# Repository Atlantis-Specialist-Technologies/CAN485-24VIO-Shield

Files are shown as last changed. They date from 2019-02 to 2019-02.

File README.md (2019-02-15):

SparkFun AST-CAN485 I/O Shield (24V)
========================================

SparkFun AST-CAN485 I/O Shield (24V)

[*SparkFun AST-CAN485 I/O Shield (24V) (14598)*](https://www.sparkfun.com/products/14598)

The SparkFun AST-CAN485 I/O Shield allows you to use the [AST-CAN485 Dev Board](https://www.sparkfun.com/products/14483) with 24VDC Inputs and Outputs, a popular voltage level for industrial automation devices as well as 5v devices. By providing screw terminals, the board can easily and safely interface with I/O in a semi-permanent manner which allows for inputs, outputs, or the board itself to be swapped out. With all pins pre-populated with either females pin headers or screw terminals, setup time is minimized.

The AST-CAN485 I/O Shield provides a socket to break out all of the I/O of the AST-CAN485 Dev Board. To make a secure connection to your industrial equipment, screw terminals come pre-soldered to the board to get you up and running in no time. The AST-CAN485 I/O Shield is designed to work in the industrial 24V environment, but has a wide supply input range of 7-24V. The board comes with input reverse voltage protection with a green and red status LEDs (green means power is connected properly, and red indicates reversed power, and blocks power to the rest of the board.

Repository Contents
-------------------

* **/Documentation** - Data sheets, additional product information
* **/Hardware** - Eagle design files (.brd, .sch)
* **/Libraries** - Libraries for use with the SparkFun AST-CAN485 I/O Shield (24V)

Documentation
--------------
* **[Library](https://github.com/Atlantis-Specialist-Technologies/AST_V24IO_Arduino_Library)** - Arduino library for the SparkFun AST-CAN485 I/O Shield (24V).
* **[Hookup Guide](https://learn.sparkfun.com/tutorials/ast-can485-io-shield-24v-hookup-guide)** - Basic hookup guide for the SparkFun AST-CAN485 I/O Shield (24V).
* **[SparkFun Fritzing repo](https://github.com/sparkfun/Fritzing_Parts)** - Fritzing diagrams for SparkFun products.

License Information
-------------------

This product is _**open source**_!

Please review the LICENSE.md file for license information.

If you have any questions or concerns on licensing, please contact techsupport@sparkfun.com.

Distributed as-is; no warranty is given.

- Your friends at SparkFun, in collaboration with Atlantis Specialist Technologies

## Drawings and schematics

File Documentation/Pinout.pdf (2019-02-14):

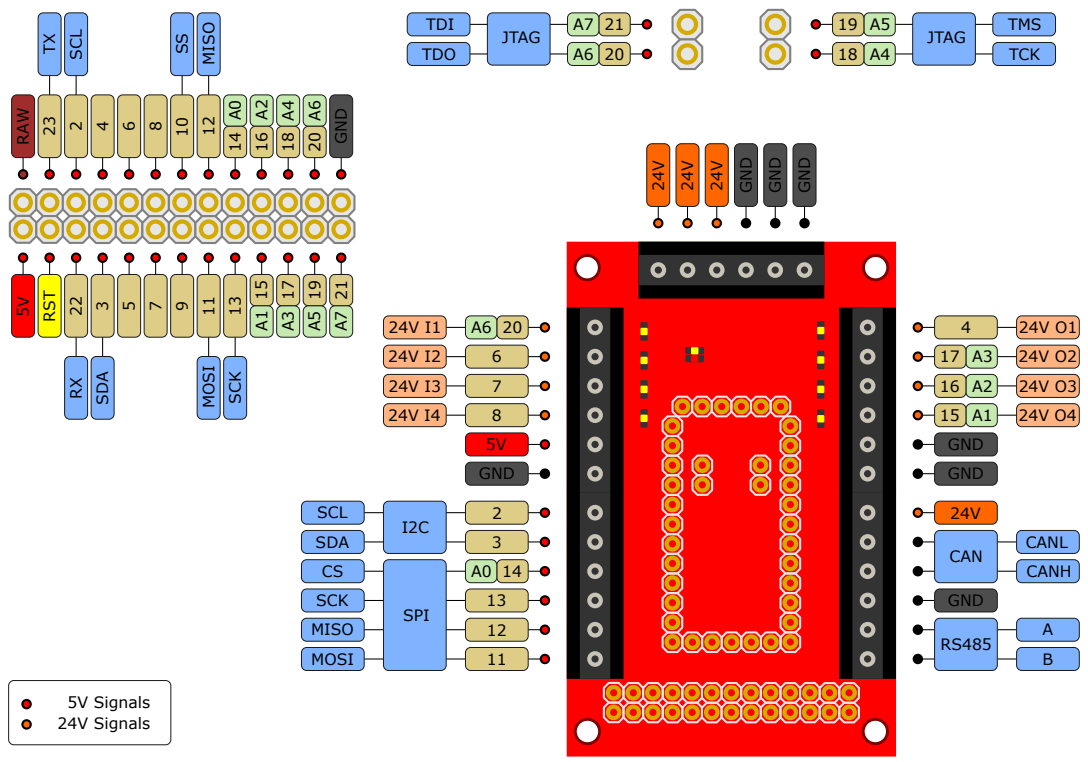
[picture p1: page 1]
TDO; TDI; JTAG; TCK; TMS; GND; CAN; CANH; CANL; SCK; MISO; MOSI; SDA; SCL; SPI; RAW; RST; 5V Signals 24V Signals

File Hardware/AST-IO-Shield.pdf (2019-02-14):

## GND

5V

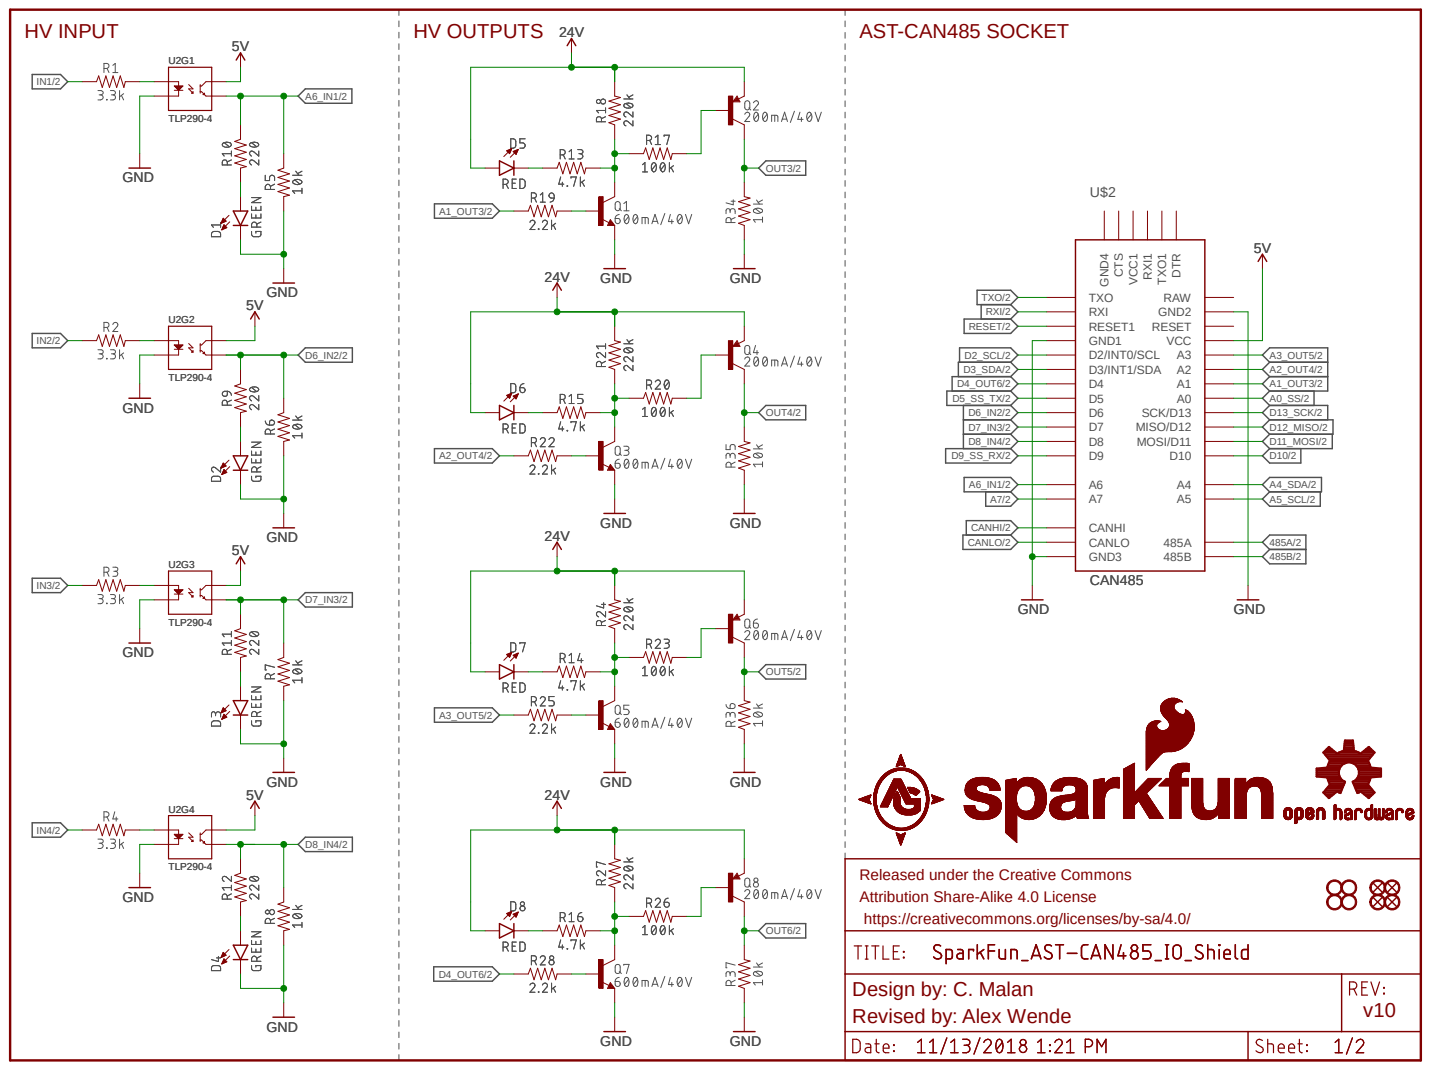
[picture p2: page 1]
GND; A0A1A2A3A4A5 CANHI CANLOCTS D2/INT0/SCL D3/INT1/SDA D4 D5 D6 D7 D8 D9; D10DTR GND1; GND2 GND3GND⁴; MISO/D12 MOSI/D11 RAW; RESET1; RESET RXI; RXI1 SCK/D13 TXO; TXO¹ VCC VCC¹; CAN485 A6A7; U2G1 TLP290-4 U2G2 TLP290-4 U2G3 TLP290-4 U2G4 TLP290-4; D4_OUT6/2; A1_OUT3/2; A2_OUT4/2; 485A/2 CANHI/2 CANLO/2; TXO/2 RXI/2 RESET/2; A3_OUT5/2; A0_SS/2 D13_SCK/2 D12_MISO/2; D11_MOSI/2 D10/2 A4_SDA/2 A7/2; A5_SCL/2; D3_SDA/2; D2_SCL/2; OUT3/2 OUT4/2 OUT5/2 OUT6/2; HV INPUT; HV OUTPUTS; AST-CAN485 SOCKET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

Released under the Creative Commons
Attribution Share-Alike 4.0 License
https://creativecommons.org/licenses/by-sa/4.0/

# VIN: 24V

# LMR14206 U1

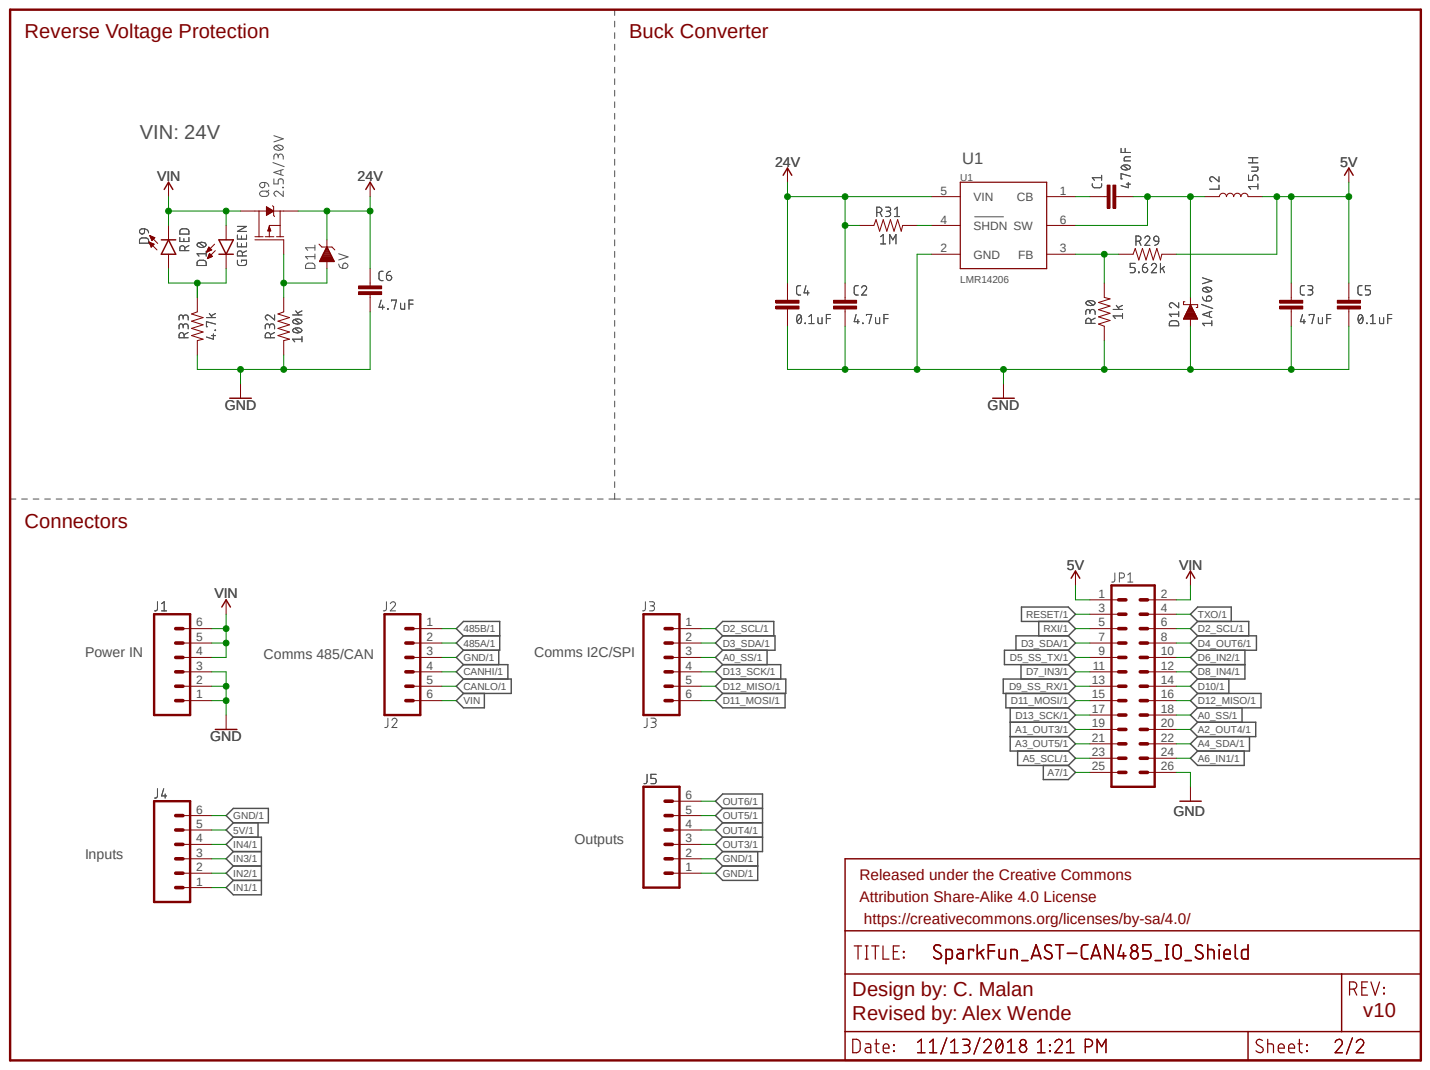
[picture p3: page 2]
Power IN; Comms 485/CAN; Comms I2C/SPI; Inputs; Outputs; GND; VIN; 3 GND 2; SHDN 4; 6 VIN 5 U1; 6 GND/1 GND/1; GND/1 GND/1; 485A/1 CANHI/1 CANLO/1; A0_SS/1 VIN; D2_SCL/1; D3_SDA/1; D13_SCK/1; D12_MISO/1; D11_MOSI/1; D4_OUT6/1; A1_OUT3/1; A2_OUT4/1 TXO/1 RXI/1 RESET/1 A3_OUT5/1; D10/1 A4_SDA/1 A7/1; A6_IN1/1 OUT3/1 OUT4/1 OUT5/1 OUT6/1; A5_SCL/1; Reverse Voltage Protection; Buck Converter; Connectors; C. Malan

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

Design by:
Revised by: Alex Wende

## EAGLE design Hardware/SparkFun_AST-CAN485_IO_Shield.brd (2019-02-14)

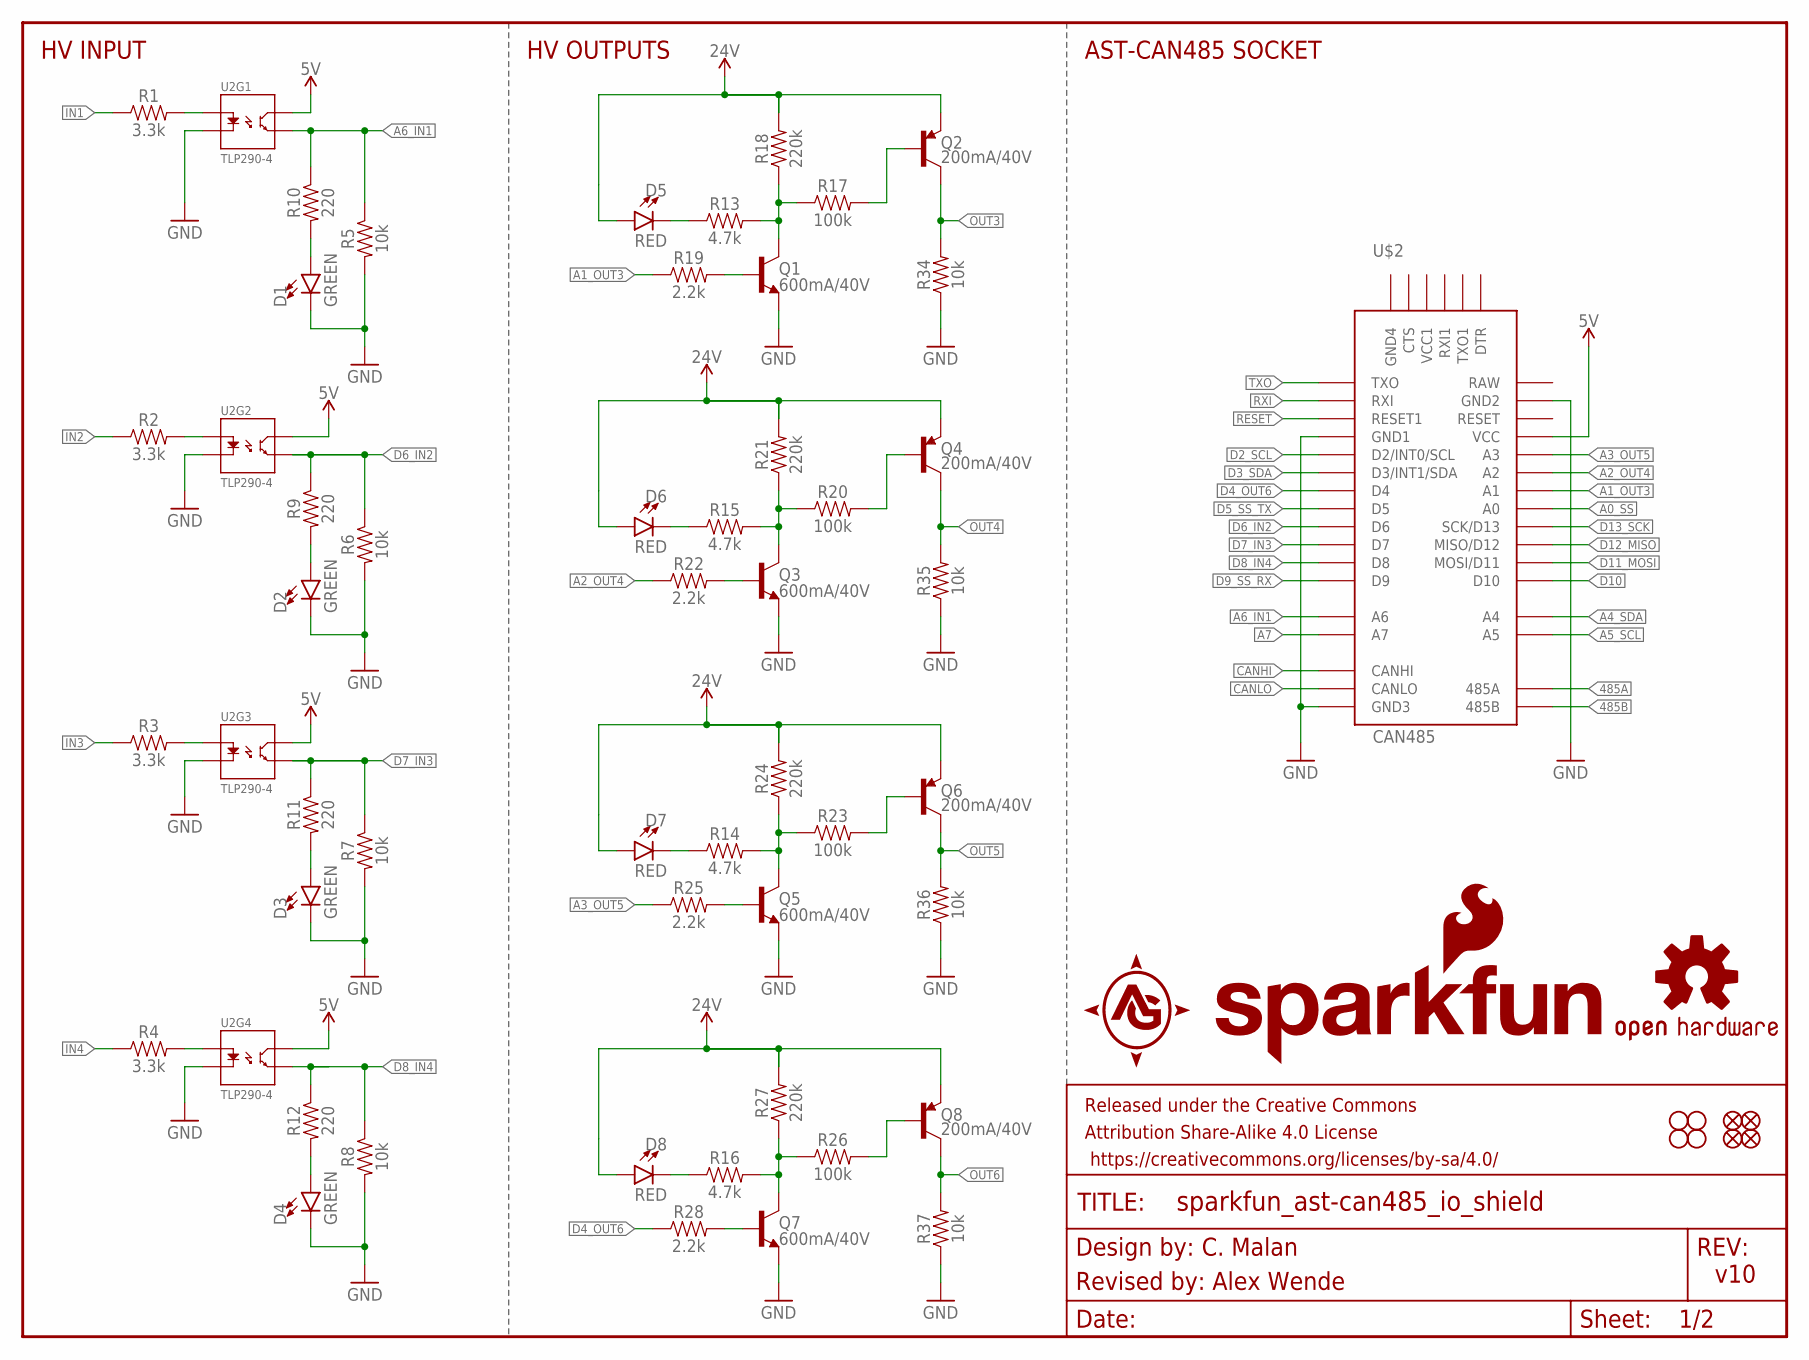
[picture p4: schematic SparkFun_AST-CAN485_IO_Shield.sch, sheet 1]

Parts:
D1, D2, D3, D4: GREEN; LED-0603
D5, D6, D7, D8: RED; LED-0603
FD1, FD2, FD3, FD4: FIDUCIALUFIDUCIAL; FIDUCIAL-MICRO
FRAME3: FRAME-LETTER; CREATIVE_COMMONS
H1, H2, H3, H4: STAND-OFF
LOGO1: OSHW-LOGOM; OSHW-LOGO-M
LOGO2: SFE_LOGO_NAME_FLAME.2_INCH; SFE_LOGO_NAME_FLAME_.2
Q1, Q3, Q5, Q7: 600mA/40V; SOT23-3
Q2, Q4, Q6, Q8: 200mA/40V; SOT23-3
R1, R2, R3, R4: 3.3k; 0603
R5, R6, R7, R8, R34, R35, R36, R37: 10k; 0603
R9, R10, R11, R12: 220; 0603
R13, R14, R15, R16: 4.7k; 0603
R17, R20, R23, R26: 100k; 0603
R18, R21, R24, R27: 220k; 0603
R19, R22, R25, R28: 2.2k; 0603
U2: TLP290-4; SO16
U$2: CAN485

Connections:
5V: U2.10 (CL1), U2.12 (CL1), U2.14 (CL1), U2.16 (CL1), U$2.VCC; also elsewhere on the board
24V: D5.A, D6.A, D7.A, D8.A, Q2.2 (E), Q4.2 (E), Q6.2 (E), Q8.2 (E), R18.2, R21.2, R24.2, R27.2; also elsewhere on the board
485A: U$2.485A; also elsewhere on the board
485B: U$2.485B; also elsewhere on the board
A0_SS: U$2.A0; also elsewhere on the board
A1_OUT3: R19.1, U$2.A1; also elsewhere on the board
A2_OUT4: R22.1, U$2.A2; also elsewhere on the board
A3_OUT5: R25.1, U$2.A3; also elsewhere on the board
A4_SDA: U$2.A4; also elsewhere on the board
A5_SCL: U$2.A5; also elsewhere on the board
A6_IN1: R5.1, R10.1, U2.15 (EM1), U$2.A6; also elsewhere on the board
A7: U$2.A7; also elsewhere on the board
CANHI: U$2.CANHI; also elsewhere on the board
CANLO: U$2.CANLO; also elsewhere on the board
D2_SCL: U$2.2 (D2/INT0/SCL); also elsewhere on the board
D3_SDA: U$2.3 (D3/INT1/SDA); also elsewhere on the board
D4_OUT6: R28.1, U$2.4 (D4); also elsewhere on the board
D5_SS_TX: U$2.5 (D5); also elsewhere on the board
D6_IN2: R6.1, R9.1, U2.13 (EM1), U$2.6 (D6); also elsewhere on the board
D7_IN3: R7.1, R11.1, U2.11 (EM1), U$2.7 (D7); also elsewhere on the board
D8_IN4: R8.1, R12.1, U2.9 (EM1), U$2.8 (D8); also elsewhere on the board
D9_SS_RX: U$2.9 (D9); also elsewhere on the board
D10: U$2.10 (D10); also elsewhere on the board
D11_MOSI: U$2.11 (MOSI/D11); also elsewhere on the board
D12_MISO: U$2.12 (MISO/D12); also elsewhere on the board
D13_SCK: U$2.13 (SCK/D13); also elsewhere on the board
GND: D1.C, D2.C, D3.C, D4.C, Q1.2 (E), Q3.2 (E), Q5.2 (E), Q7.2 (E), R5.2, R6.2, R7.2, R8.2, R34.1, R35.1, R36.1, R37.1, U2.2 (C1), U2.4 (C1), U2.6 (C1), U2.8 (C1), U$2.GND1, U$2.GND2, U$2.GND3; also elsewhere on the board
IN1: R1.1; also elsewhere on the board
IN2: R2.1; also elsewhere on the board
IN3: R3.1; also elsewhere on the board
IN4: R4.1; also elsewhere on the board
unnamed: R1.2, U2.1 (A1)
unnamed: R3.2, U2.5 (A1)
unnamed: R4.2, U2.7 (A1)
unnamed: R2.2, U2.3 (A1)
unnamed: Q2.1 (B), R17.2
unnamed: Q1.3 (C), R13.2, R17.1, R18.1
unnamed: Q1.1 (B), R19.2
unnamed: Q4.1 (B), R20.2
unnamed: Q3.3 (C), R15.2, R20.1, R21.1
unnamed: D2.A, R9.2
unnamed: Q3.1 (B), R22.2
unnamed: Q6.1 (B), R23.2
unnamed: Q5.3 (C), R14.2, R23.1, R24.1
unnamed: Q5.1 (B), R25.2
unnamed: Q8.1 (B), R26.2
unnamed: Q7.3 (C), R16.2, R26.1, R27.1
unnamed: Q7.1 (B), R28.2
unnamed: D1.A, R10.2
unnamed: D4.A, R12.2
unnamed: D3.A, R11.2
unnamed: D5.C, R13.1
unnamed: D7.C, R14.1
unnamed: D6.C, R15.1
unnamed: D8.C, R16.1
OUT3: Q2.3 (C), R34.2; also elsewhere on the board
OUT4: Q4.3 (C), R35.2; also elsewhere on the board
OUT5: Q6.3 (C), R36.2; also elsewhere on the board
OUT6: Q8.3 (C), R37.2; also elsewhere on the board
RESET: U$2.RST1 (RESET1); also elsewhere on the board
RXI: U$2.RXI; also elsewhere on the board
TXO: U$2.TXO; also elsewhere on the board

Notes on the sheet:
HV INPUT
HV OUTPUTS
AST-CAN485 SOCKET
C. Malan
Revised by: Alex Wende
v10

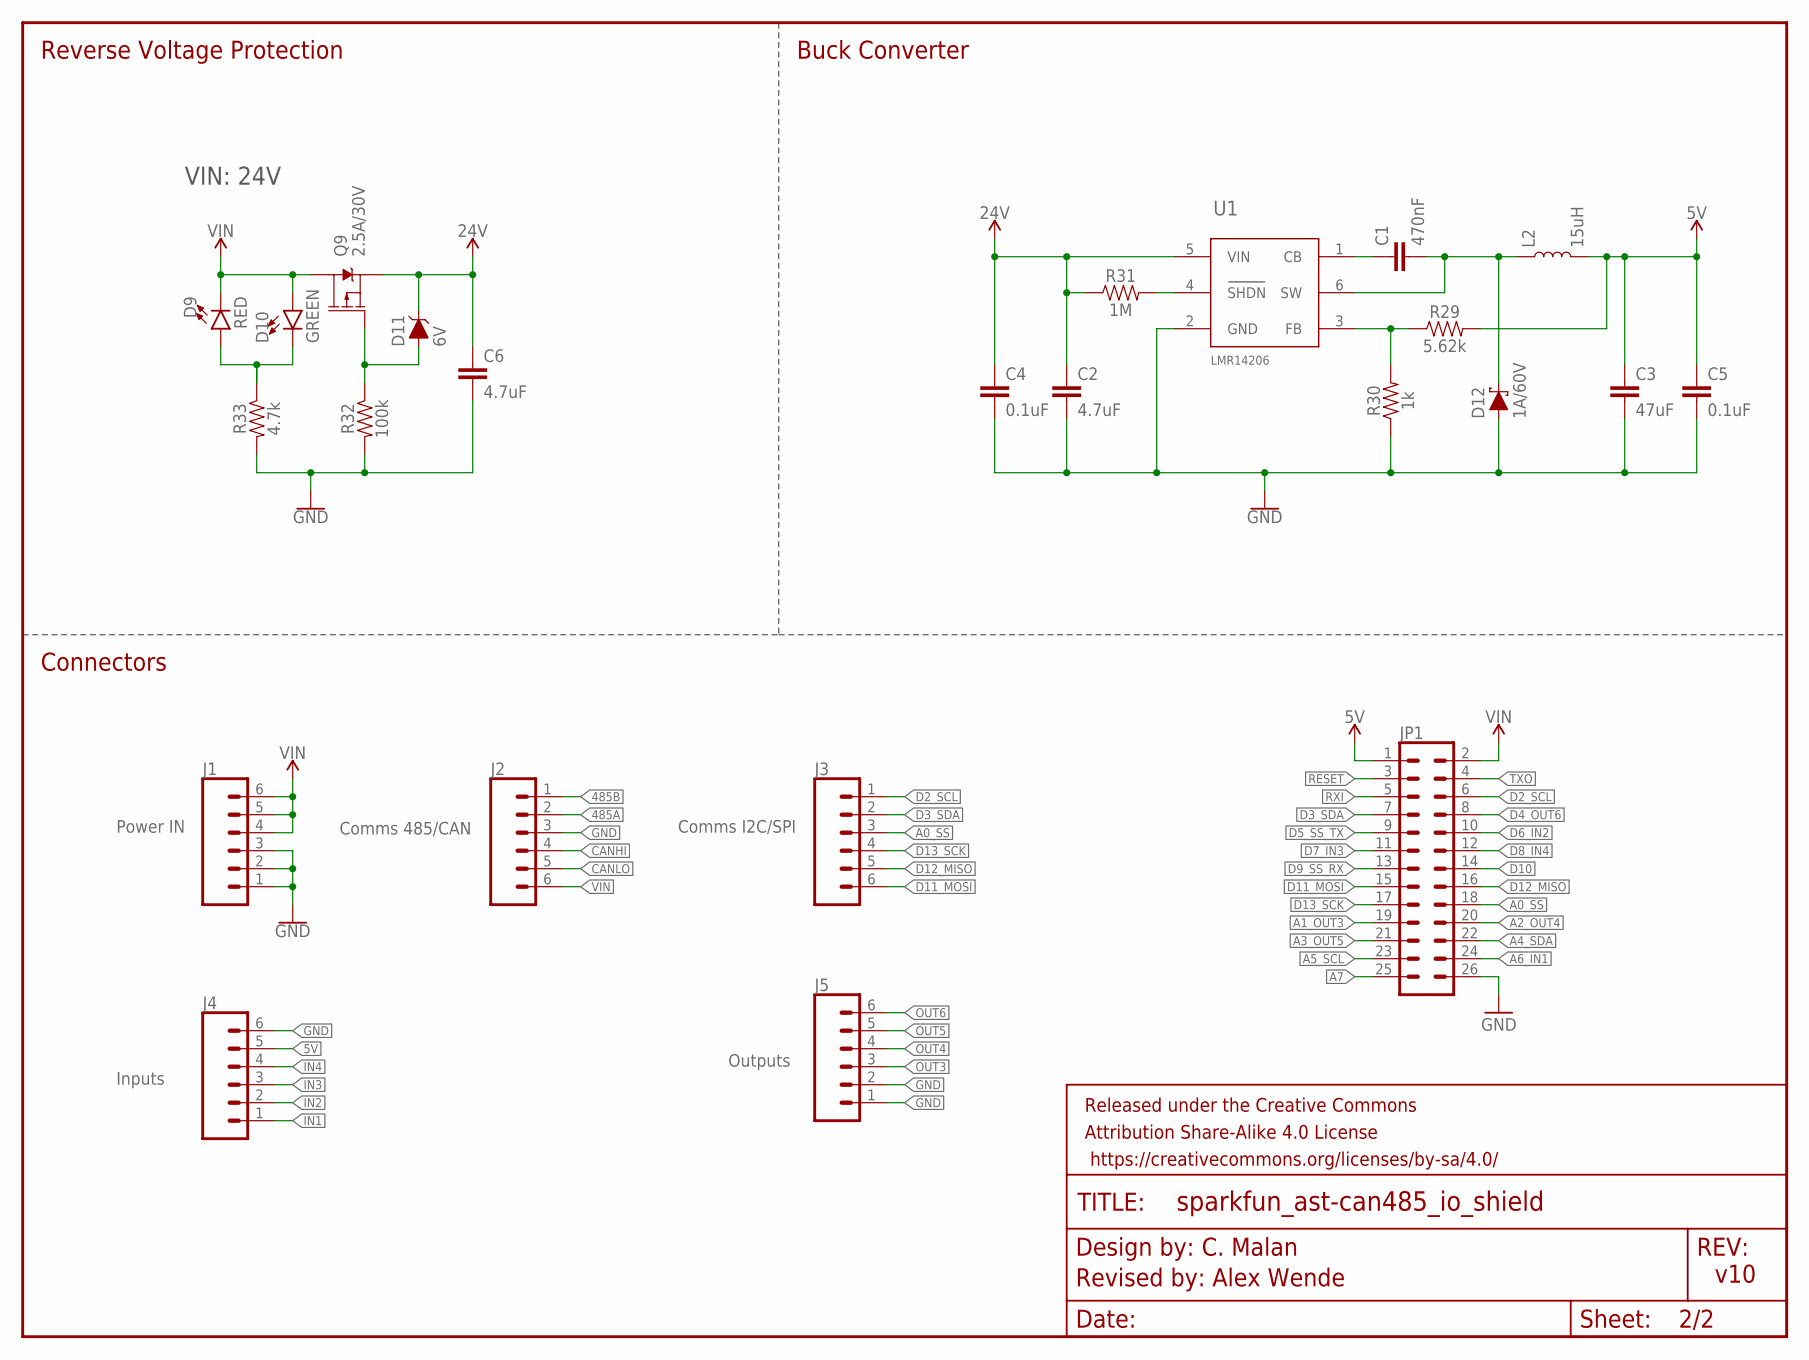
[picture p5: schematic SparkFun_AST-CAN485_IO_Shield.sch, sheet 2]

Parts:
C1: 470nF; 0603
C2, C6: 4.7uF; 0603
C3: 47uF; 0805
C4, C5: 0.1uF; 0603
D9: RED; LED-0603
D10: GREEN; LED-0603
D11: 6V; SOT23-3
D12: 1A/60V; DIODE-MICRO-SMP
FRAME1: FRAME-LETTERNO_PACKAGE; DUMMY
J1, J2, J3, J4, J5: CONN_063.5MM-6; SCREWTERMINAL-3.5MM-6
JP1: CONN_13X22X13; 2X13
L2: 15uH; INDUCTOR_LQH32
Q9: 2.5A/30V; SOT23-3
R29: 5.62k; 0603
R30: 1k; 0603
R31: 1M; 0603
R32: 100k; 0603
R33: 4.7k; 0603
U1: LMR14206; SOT23-6

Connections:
5V: C3.1, C5.1, J4.5, JP1.1, L2.P$2 (2), R29.2; also elsewhere on the board
24V: C2.1, C4.1, C6.1, D11.3 (C), Q9.2 (S), R31.1, U1.5 (VIN); also elsewhere on the board
485A: J2.2; also elsewhere on the board
485B: J2.1; also elsewhere on the board
A0_SS: J3.3, JP1.18; also elsewhere on the board
A1_OUT3: JP1.19; also elsewhere on the board
A2_OUT4: JP1.20; also elsewhere on the board
A3_OUT5: JP1.21; also elsewhere on the board
A4_SDA: JP1.22; also elsewhere on the board
A5_SCL: JP1.23; also elsewhere on the board
A6_IN1: JP1.24; also elsewhere on the board
A7: JP1.25; also elsewhere on the board
CANHI: J2.4; also elsewhere on the board
CANLO: J2.5; also elsewhere on the board
D2_SCL: J3.1, JP1.6; also elsewhere on the board
D3_SDA: J3.2, JP1.7; also elsewhere on the board
D4_OUT6: JP1.8; also elsewhere on the board
D5_SS_TX: JP1.9; also elsewhere on the board
D6_IN2: JP1.10; also elsewhere on the board
D7_IN3: JP1.11; also elsewhere on the board
D8_IN4: JP1.12; also elsewhere on the board
D9_SS_RX: JP1.13; also elsewhere on the board
D10: JP1.14; also elsewhere on the board
D11_MOSI: J3.6, JP1.15; also elsewhere on the board
D12_MISO: J3.5, JP1.16; also elsewhere on the board
D13_SCK: J3.4, JP1.17; also elsewhere on the board
FB: R29.1, R30.2, U1.3 (FB)
GND: C2.2, C3.2, C4.2, C5.2, C6.2, D12.A, J1.1, J1.2, J1.3, J2.3, J4.6, J5.1, J5.2, JP1.26, R30.1, R32.2, R33.2, U1.2 (GND); also elsewhere on the board
IN1: J4.1; also elsewhere on the board
IN2: J4.2; also elsewhere on the board
IN3: J4.3; also elsewhere on the board
IN4: J4.4; also elsewhere on the board
unnamed: D9.A, D10.C, R33.1
unnamed: D11.1 (A), Q9.1 (G), R32.1
OUT3: J5.3; also elsewhere on the board
OUT4: J5.4; also elsewhere on the board
OUT5: J5.5; also elsewhere on the board
OUT6: J5.6; also elsewhere on the board
RESET: JP1.3; also elsewhere on the board
RXI: JP1.5; also elsewhere on the board
SHDN: R31.2, U1.4 (SHDN)
TXO: JP1.4; also elsewhere on the board
VBOOT: C1.1, U1.1 (CB)
VIN: D9.C, D10.A, J1.4, J1.5, J1.6, J2.6, JP1.2, Q9.3 (D)
VSW: C1.2, D12.C, L2.P$1 (1), U1.6 (SW)

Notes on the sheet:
Power IN
Comms 485/CAN
Comms I2C/SPI
Inputs
Outputs
Reverse Voltage Protection
Buck Converter
Connectors
v10
C. Malan
Revised by: Alex Wende
VIN: 24V

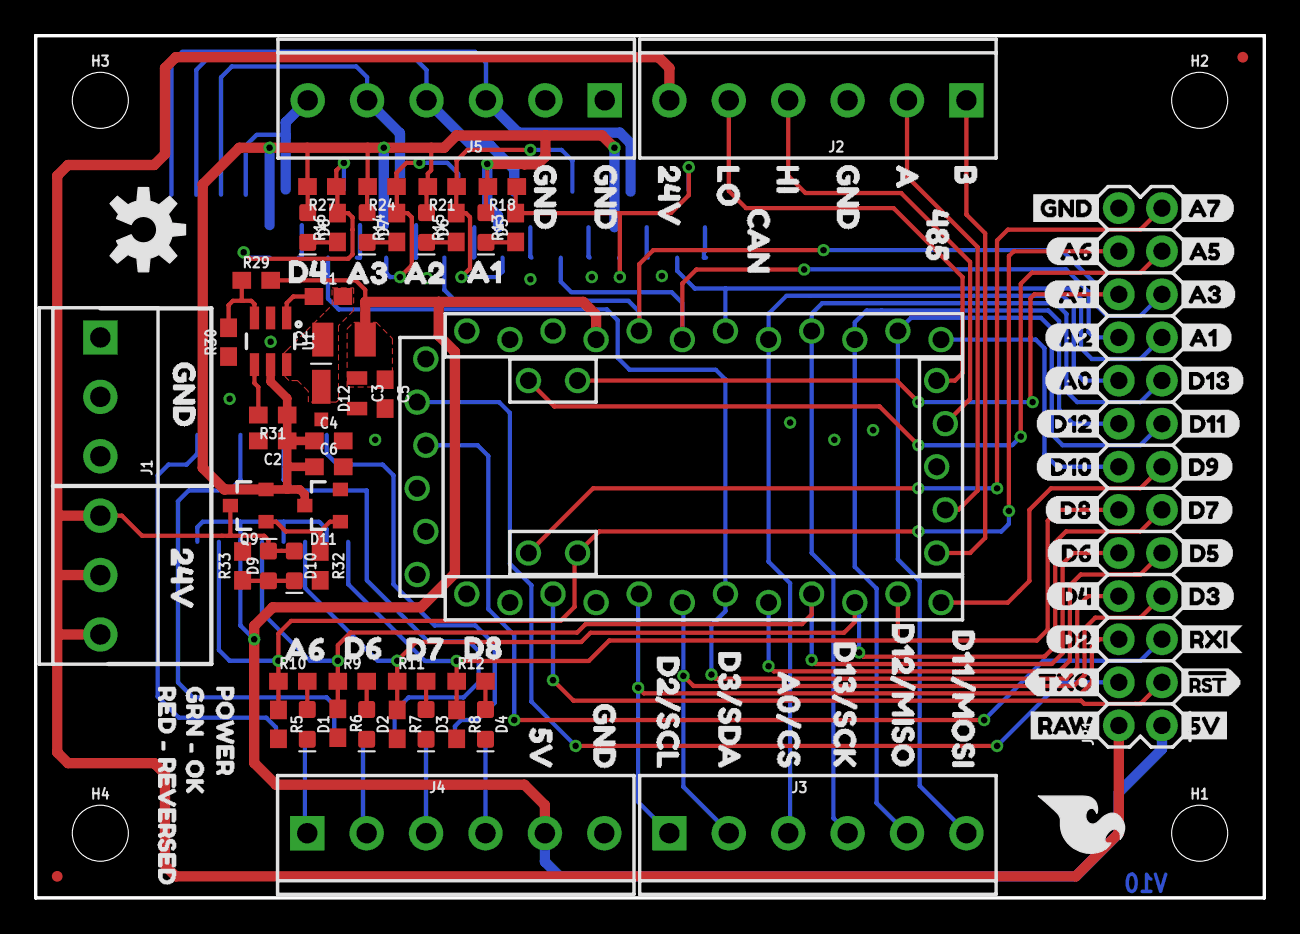
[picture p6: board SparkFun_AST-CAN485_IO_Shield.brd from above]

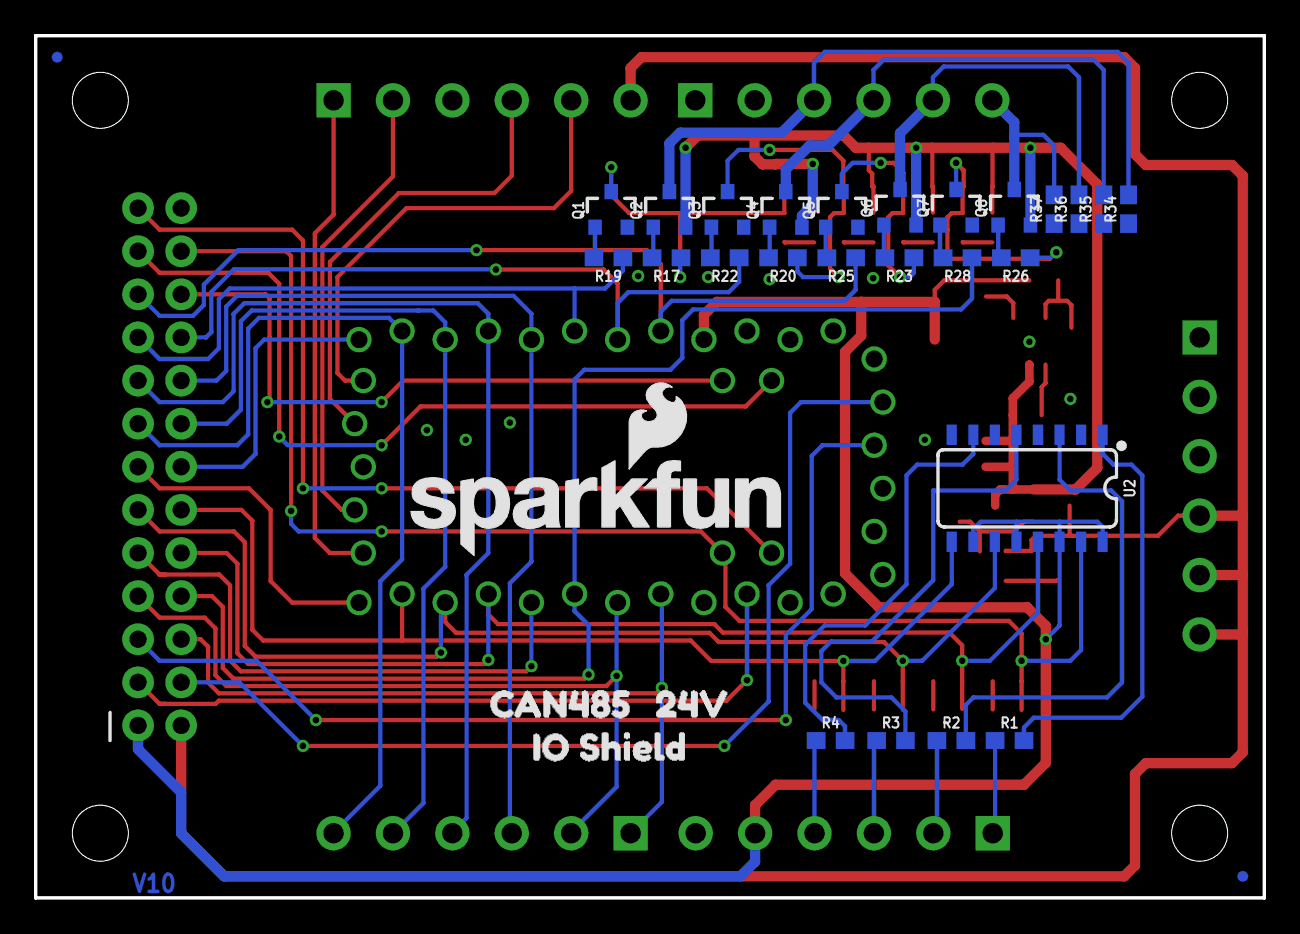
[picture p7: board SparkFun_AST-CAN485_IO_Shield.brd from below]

Board: 2 copper layers, 72.4 x 50.8 mm, 147 parts (31 on the bottom side), 69 nets.

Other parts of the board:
U$1: #RST27
U$3: 5V26
U$4: A60
U$5: D319
U$6: D517
U$7: D715
U$8: D913
U$9: D1111
U$10: D139
U$11: A17
U$12: A35
U$13: A53
U$14: A71
U$15, U$29, U$44, U$45, U$49, U$55: GND0
U$16: RAW25
U$17: RXI10
U$18: A41
U$19: A22
U$20: A03
U$21: D124
U$22: D105
U$23: D86
U$24: D67
U$25: D48
U$26: D29
U$27: TXO11
U$28: 5V19
U$30: D818
U$31: D717
U$32: D616
U$33: A615
U$34: D2#SCL20
U$35: D3#SDA21
U$36: A0#CS22
U$37: D13#SCK23
U$38: D12#MISO24
U$39: D11#MOSI25
U$40: D413
U$41: A311
U$42: _A210
U$43: A112
U$46, U$54, U$61: 24V1
U$47: LO2
U$48: HI3
U$50: A6
U$51: B7
U$52: 4858
U$53: CAN4
U$56: RED_#_REVERSED3
U$57: GRN_#_OK1
U$58: POWER0
U$59: CAN4850
U$60: SFE_LOGO_FLAME_.2
U$62: IO_SHIELD2

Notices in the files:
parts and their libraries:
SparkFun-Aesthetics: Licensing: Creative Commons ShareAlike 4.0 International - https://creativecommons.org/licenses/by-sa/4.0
